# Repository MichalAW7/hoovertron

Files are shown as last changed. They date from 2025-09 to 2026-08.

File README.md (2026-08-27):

# Hoovertron: A Device for the Quantitative Measurement of Hoover's Sign

This repository contains the complete design files and software for the Hoovertron, a portable, floor-based device for the standardised, quantitative measurement of Hoover's sign. It provides a reliable, objective tool to aid diagnosis of functional leg weakness, a common feature of Functional Neurological Disorder (FND).

Based on: *Quantitative Measurement of Hoover's sign: development of a standardised sensor, interface procedure and testing in healthy individuals*.

## Repository Structure

```
hoovertron/
├── hardware/
│   ├── mechanical/          # SolidEdge source + STL/3MF/GCODE exports
│   │   ├── source/v1-main-part/
│   │   ├── source/v2-revised/
│   │   └── exports/{stl,3mf,gcode}/
│   └── pcb/
│       ├── src/             # Altium Designer source (SchDoc, PcbDoc, SchLib, PcbLib, PrjPcb)
│       └── outputs/         # Gerbers / CAM (generated, gitignored)
├── firmware/
│   ├── HVR_code_BLE_V3/     # Canonical Arduino Nano 33 BLE firmware (latest, with dummy-load fix)
│   └── archive/
│       ├── HVR_code_BLE_V2/ # Previous BLE version
│       ├── HVR_code_BLE_V1/
│       ├── HVR_code_v5/
│       └── FND_code_v4/
├── software/
│   ├── gui/                 # Canonical desktop GUI (Python + PyQt5 + bleak)
│   │   ├── main.py
│   │   ├── hoover_logic.py, ui_layout.py, config.py
│   │   ├── hoover_backend/  # ble_mixin, data_mixin, file_mixin, serial_mixin
│   │   ├── ui_components/   # menu_bar, patient_tab, results_tab, step_tabs
│   │   ├── images/
│   │   ├── Documentation/   # ARCHITECTURE, QUICK_START, etc.
│   │   ├── requirements.txt
│   │   └── HooverTron.spec / compile_app.bat
│   └── archive/
│       ├── bluetooth-v1/    # Legacy single-file BLE prototype
│       ├── bluetooth-v2/    # Pre-stylesheet modular version
│       └── gui-monolith/    # HooverTron.py monolith (pre-modular)
├── docs/
│   ├── manual/              # hoovertron_manual.md/.tex, canva_prompt.md
│   ├── images/              # Consolidated screenshots/infographics
│   └── screenshots/
├── .gitignore
└── LICENSE.md
```

## Hardware

### Mechanical
Custom 3D-printed housing isolates the heel on the sensor. Source in `hardware/mechanical/source/` (SolidEdge `.par`), printable exports in `hardware/mechanical/exports/` (`stl/` for printing, `3mf` for project, `gcode/` for slicer). See `hardware/mechanical/README.md` for print settings.

### Electronics
Custom PCB (Altium) in `hardware/pcb/src/`:
- **MCU:** Arduino Nano 33 BLE (or Nano Every for wired) - data acquisition & BLE/Serial
- **Sensor:** Ohmite FSR01CE force sensing resistor in voltage divider with 180 Ω, buffered via MCP6002 voltage follower, 3x 100nF decoupling/filter
- **Power:** USB or battery pack (V3 firmware pulses D2 with 100-220Ω dummy load to keep pack awake)

Gerber/BOM outputs are in `hardware/pcb/outputs/` (regenerable, ignored by git).

## Firmware

Canonical: `firmware/HVR_code_BLE_V3/HVR_code_BLE_V3.ino` (ArduinoBLE, 12-bit ADC 0-4095, dual-channel A0/A1, exponential force calibration `0.8259*exp(0.8623*V)...`, bilinear LPF `alpha=(2-2π0.001f)/(2+2π0.001f)`, BLE service `180D` char `2A37`, serial `F<freq>` command).

Upload with Arduino IDE (board: Nano 33 BLE, baud 115200).

Legacy versions in `firmware/archive/`.

## Software

### Requirements
```bash
pip install -r software/gui/requirements.txt
# PyQt5>=5.15.0, bleak>=0.20.0, qasync, numpy, matplotlib, pyqtgraph
```

### Run
```bash
python software/gui/main.py
# or build exe:
software/gui/compile_app.bat   # uses HooverTron.spec
```

Features: BLE/Serial connect, real-time force plot (N vs s), region select for max voluntary/involuntary, IV/V ratio, CSV logging.

### Documentation
- `software/gui/Documentation/QUICK_START.md` - install & run
- `software/gui/Documentation/ARCHITECTURE.md` - backend mixins + UI components
- `docs/manual/hoovertron_manual.md` - full manual

## Data Privacy
`patient data.csv` is gitignored. Do not commit patient data. Use anonymized examples only.

## License
MIT - see [LICENSE.md](LICENSE.md)

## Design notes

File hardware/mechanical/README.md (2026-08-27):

# Mechanical - 3D Printed Parts

Source SolidEdge `.par` in `source/`, exports in `exports/`. Print `exports/stl` at 0.2mm, PLA, 20% infill. See original SolidEdge files for tolerances.

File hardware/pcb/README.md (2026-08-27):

# PCB - Altium

Source in `src/`: Sheet1.SchDoc, PCB1.PcbDoc, etc. Open `Hoovertron_wired.PrjPcb` in Altium. Outputs regenerable in `outputs/` (Gerbers, drills).

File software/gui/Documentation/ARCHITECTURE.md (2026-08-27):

# HooverTron BLE Architecture

## System Overview

```
┌─────────────────────────────────────────────────────────────┐
│                    HooverTron BLE System                     │
└─────────────────────────────────────────────────────────────┘

┌──────────────────────┐         WIRELESS          ┌──────────────────────┐
│   Arduino Nano 33    │◄────────  BLE  ──────────►│   Python Application │
│        BLE           │      (~10-30 meters)       │      (PyQt5)         │
└──────────────────────┘                            └──────────────────────┘
         │                                                      │
         │ Reads Sensors                                       │ Displays
         ▼                                                      ▼
┌──────────────────────┐                            ┌──────────────────────┐
│  Force Sensors       │                            │  Real-time Graphs    │
│  - Sensor 1 (A0)     │                            │  - Extension Force   │
│  - Sensor 2 (A1)     │                            │  - Voluntary Force   │
└──────────────────────┘                            │  - Involuntary Force │
                                                     │  - Data Analysis     │
                                                     │  - Database          │
                                                     └──────────────────────┘
```

## Data Flow

```
┌─────────────────────────────────────────────────────────────────────┐
│                          Data Processing Pipeline                    │
└─────────────────────────────────────────────────────────────────────┘

ARDUINO SIDE:
─────────────
1. Analog Read (A0, A1)
   ▼
2. 12-bit ADC Conversion (0-4095)
   ▼
3. Voltage Scaling (5V equivalent)
   ▼
4. Force Calibration (Exponential formula)
   ▼
5. Digital Filtering (Alpha/Beta filter)
   ▼
6. Format as CSV String
   ▼
7. BLE Transmission (Notify)
   │
   │  <<< WIRELESS BLUETOOTH >>>
   │
   ▼

PYTHON SIDE:
────────────
8. BLE Notification Received
   ▼
9. Data Buffering
   ▼
10. Parse CSV String
    ▼
11. Update Data Arrays
    ▼
12. Update Real-time Graphs
    ▼
13. Calculate Statistics
    ▼
14. Save to Database/File
```

## BLE Communication

```
┌─────────────────────────────────────────────────────────────────────┐
│                      Bluetooth Low Energy (BLE)                      │
└─────────────────────────────────────────────────────────────────────┘

SERVICE: "180D"
├── CHARACTERISTIC: "2A37"
    ├── Properties: READ | NOTIFY
    ├── Max Size: 64 bytes
    ├── Data Format: "Time,Force1,Force2,FilteredForce1"
    └── Update Rate: ~100 Hz (every 10ms)

CONNECTION FLOW:
─────────────────
Arduino                             Python App
   │                                    │
   │ 1. BLE.begin()                     │
   │ 2. Set name "HooverTron"           │
   │ 3. Advertise service               │
   │                                    │
   │              ◄─────────────── 4. Scan for devices
   │              ──────────────► 5. Device found!
   │              ◄─────────────── 6. Connect request
   │ 7. Connection accepted             │
   │              ──────────────► 8. Start notifications
   │                                    │
   │ 9. Loop: read sensors              │
   │ 10. Send data via BLE              │
   │              ──────────────► 11. Receive notification
   │                                 12. Process & display
   │                                    │
   │ (continuous data stream...)        │
   │              ──────────────►       │
   │              ──────────────►       │
   │                                    │
   │              ◄─────────────── 13. Disconnect request
   │ 14. Close connection               │
```

## Component Architecture

```
┌─────────────────────────────────────────────────────────────────────┐
│                           Arduino Firmware                           │
└─────────────────────────────────────────────────────────────────────┘

LIBRARIES:
- ArduinoBLE.h          → Bluetooth communication

MAIN COMPONENTS:
- BLEService            → Container for characteristics
- BLECharacteristic     → Data channel
- Sensor Reading        → analogRead() from A0, A1
- Digital Filter        → First-order filter implementation
- Data Formatting       → CSV string builder

LOOP CYCLE (every 10ms):
1. Check for BLE connection
2. Read sensors
3. Apply calibration
4. Apply filtering
5. Format data
6. Transmit via BLE

┌─────────────────────────────────────────────────────────────────────┐
│                        Python Application                            │
└─────────────────────────────────────────────────────────────────────┘

LIBRARIES:
- PyQt5                 → GUI framework
- bleak                 → BLE communication
- qasync                → Async/await with PyQt5
- numpy                 → Data processing
- matplotlib            → Plotting

MAIN COMPONENTS:
- HooverTronWindow      → Main application class
- BleakClient           → BLE connection handler
- BleakScanner          → Device discovery
- UI Layout             → PyQt5 GUI elements
- Data Arrays           → Force and time data storage
- File I/O              → CSV and config management
- Database Manager      → Patient data storage

EVENT LOOP:
- QEventLoop (qasync)   → Handles both GUI and async BLE events
```

## File Organization

```
AntiGravity/
├── Arduino Firmware
│   └── HVR_code_BLE_V1/
│       └── HVR_code_BLE_V1.ino      ← BLE-enabled firmware
│
├── Python Application
│   ├── main.py                       ← Entry point (async event loop)
│   ├── hoover_logic.py               ← BLE logic + data processing
│   ├── ui_layout.py                  ← GUI definition
│   └── config.py                     ← Configuration paths
│
├── Setup & Dependencies
│   ├── requirements.txt              ← Python packages
│   └── install_dependencies.bat      ← Windows installer
│
└── Documentation
    ├── README_BLE.md                 ← Full documentation
    ├── QUICK_START.md                ← Getting started guide
    ├── CHANGES_SUMMARY.md            ← What changed
    └── ARCHITECTURE.md               ← This file
```

## Key Design Decisions

### Why These UUIDs?
- **Service 180D**: Standard "Heart Rate" service UUID
  - Chosen for compatibility and simplicity
  - Repurposed for sensor data transmission
  
- **Characteristic 2A37**: Standard "Heart Rate Measurement"
  - READ | NOTIFY properties
  - Perfect for continuous data streaming

### Why bleak Library?
- Cross-platform (Windows, macOS, Linux)
- Modern async/await API
- Well-maintained and documented
- Native OS BLE stack integration

### Why qasync?
- Bridges asyncio and PyQt5
- Allows async BLE operations without blocking GUI
- Clean integration of both event loops

### Why Keep Serial?
- Debugging during development
- Firmware verification
- Troubleshooting sensor issues
- Future diagnostics

## Performance Characteristics

**Latency:**
- BLE notification delay: ~10-20ms
- Processing time: <1ms
- GUI update rate: ~100 Hz
- Total system latency: ~20-30ms

**Throughput:**
- Data packet size: ~30 bytes
- Update frequency: 100 Hz
- Bandwidth usage: ~3 KB/s
- BLE capacity: Up to 1 MB/s

**Range:**
- Indoor: 10-15 meters
- Outdoor: 20-30 meters
- Through walls: 5-10 meters

**Power Consumption:**
- BLE transmission: ~15 mA
- Sensor reading: ~5 mA
- Microcontroller: ~10 mA
- **Total: ~30 mA** (can run on battery)

## Security Considerations

**Current Implementation:**
- No encryption (open connection)
- No authentication required
- Any device can connect

**Future Enhancements:**
- Pairing/bonding support
- Encrypted characteristic
- Password protection
- MAC address filtering

## Comparison: Serial vs BLE

```
┌──────────────────┬────────────────────┬────────────────────┐
│    Feature       │    Serial/USB      │        BLE         │
├──────────────────┼────────────────────┼────────────────────┤
│ Connection       │ Wired (USB cable)  │ Wireless (BLE)     │
│ Range            │ <5 meters          │ 10-30 meters       │
│ Mobility         │ Tethered           │ Free movement      │
│ Power            │ USB powered        │ Battery possible   │
│ Latency          │ <5ms               │ ~20ms              │
│ Bandwidth        │ 115200 baud        │ ~1 Mbps            │
│ Setup            │ COM port selection │ Auto-discovery     │
│ Reliability      │ Very high          │ High               │
│ Interference     │ None               │ Possible (rare)    │
│ Multiple devices │ Complex            │ Easier             │
└──────────────────┴────────────────────┴────────────────────┘
```

## Future Expansion Possibilities

1. **Multiple Sensors:**
   - Connect multiple Arduino units
   - Synchronized data collection
   - Comparative analysis

2. **Mobile App:**
   - iOS/Android application
   - Tablet-based interface
   - Cloud data sync

3. **Data Analytics:**
   - Machine learning integration
   - Pattern recognition
   - Automated diagnostics

4. **Remote Monitoring:**
   - WiFi gateway
   - Internet connectivity
   - Remote expert consultation

5. **Enhanced Features:**
   - Battery level indicator
   - Signal strength display
   - Automatic reconnection
   - Data logging on Arduino

## Conclusion

The BLE implementation provides a modern, wireless solution while maintaining 100% functional compatibility with the original serial-based system. The modular architecture allows for easy future enhancements and expansions.

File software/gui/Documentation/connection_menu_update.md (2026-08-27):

# HooverTron Connection Menu Update

## Summary of Changes

### 1. New "Connection" Menu Tab
- Created a new menu tab called "Connection" positioned between "Database" and "Help"
- Moved Bluetooth device management from "Edit" menu to this new "Connection" menu
- The menu name is "Bluetooth" instead of "BLE Device" for clarity

### 2. Automatic Connection Feature
- The application now automatically scans for devices with "hoovertron" in the name (case-insensitive)
- When found, the device is:
  - Automatically selected
  - Marked with a ★ symbol in the device list
  - Automatically connected
- If no hoovertron device is found, the app performs a regular scan and displays all available devices

### 3. Manual Connection Fallback
- If automatic connection fails, users can still manually:
  - Scan for devices using "Scan for Devices" option
  - Select any available BLE device from the list
  - Click "Connect" to establish connection

### 4. Files Modified
- **menu_bar.py**: Added "Connection" menu and integrated BLE device manager
- **add_ble_device.py**: Added auto_scan_and_connect() method for automatic connection
- **hoover_logic.py**: Recreated main window class integrating all backend mixins

### 5. How It Works
1. Application starts
2. BLE manager automatically scans for devices
3. Looks for "hoovertron" device
4. If found: auto-selects and connects
5. If not found: displays message and shows all available devices
6. User can manually connect if needed

### 6. Status Messages
The status bar shows:
- "Searching for HooverTron device..." during scan
- "Found HooverTron: [name]. Auto-connecting..." when device is found
- "HooverTron device not found. Please scan and connect manually." if not found
- Connection status updates

## Usage
1. Start the application
2. The Connection menu appears between Database and Help
3. Click Connection → Bluetooth to see device options
4. The hoovertron device (if available) will be auto-selected and connected
5. If manual connection needed: Click "Scan for Devices" then "Connect"

## Benefits
- Streamlined workflow with automatic connection
- Clear menu organization with dedicated Connection tab
- Better user experience with status messages
- Fallback to manual connection ensures flexibility

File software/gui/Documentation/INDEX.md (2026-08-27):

# 📡 HooverTron BLE - Documentation Index

Welcome to the HooverTron Bluetooth Low Energy implementation! This index will guide you to the right documentation for your needs.

---

## 🚀 Getting Started (First Time Users)

**Start Here → [QUICK_START.md](QUICK_START.md)**
- Step-by-step setup instructions
- Arduino firmware upload guide
- Python installation
- First connection tutorial
- Basic troubleshooting

**Estimated Time:** 10-15 minutes

---

## 📚 Documentation Guide

### For Users

| Document | Purpose | When to Read |
|---|---|---|
| **[QUICK_START.md](QUICK_START.md)** | Quick setup & usage | First time setup |
| **[README_BLE.md](README_BLE.md)** | Complete user manual | Detailed information needed |
| **Troubleshooting** (in README_BLE.md) | Fix common issues | When things don't work |

### For Developers

| Document | Purpose | When to Read |
|---|---|---|
| **[ARCHITECTURE.md](ARCHITECTURE.md)** | System design & data flow | Understanding the system |
| **[CHANGES_SUMMARY.md](CHANGES_SUMMARY.md)** | What changed from serial | Migration from old version |
| **Code files** | Implementation details | Modifying the code |

---

## 📁 File Structure & Purpose

### Arduino Firmware
```
HVR_code_BLE_V1/
└── HVR_code_BLE_V1.ino         Arduino code with BLE support
```

### Python Application
```
main.py                          Entry point - run this to start
hoover_logic.py                  BLE communication & data processing  
ui_layout.py                     GUI interface definition
config.py                        Configuration file paths
add_comport.py                   Legacy COM port utilities
```

### Setup Scripts
```
requirements.txt                 Python dependencies list
install_dependencies.bat         Windows installer script
```

### Documentation
```
INDEX.md                         This file - start here
QUICK_START.md                   Fast setup guide
README_BLE.md                    Complete documentation
ARCHITECTURE.md                  Technical design details
CHANGES_SUMMARY.md               Migration guide
```

---

## 🎯 Common Tasks

### "I want to set this up for the first time"
→ Read **[QUICK_START.md](QUICK_START.md)**

### "Something isn't working"
→ Check **Troubleshooting** section in **[README_BLE.md](README_BLE.md)**

### "I need to understand how BLE communication works"
→ Read **[ARCHITECTURE.md](ARCHITECTURE.md)**

### "I'm upgrading from the serial version"
→ Read **[CHANGES_SUMMARY.md](CHANGES_SUMMARY.md)**

### "I want to modify the code"
→ Read **[ARCHITECTURE.md](ARCHITECTURE.md)** first, then examine the code files

### "I need installation help"
→ Run **install_dependencies.bat** OR see Setup sections in **[QUICK_START.md](QUICK_START.md)**

### "I want to know what's different from before"
→ Read **[CHANGES_SUMMARY.md](CHANGES_SUMMARY.md)**

---

## ⚡ Quick Reference

### System Requirements
- **Hardware:** Arduino Nano 33 BLE + Bluetooth 4.0+ computer
- **Software:** Python 3.7+ | Arduino IDE 1.8.10+
- **OS:** Windows 10+, macOS 10.15+, or Linux with BlueZ

### Key Information
- **Device Name:** HooverTron
- **BLE Service UUID:** 180D
- **BLE Characteristic UUID:** 2A37
- **Data Format:** `Time,Force1,Force2,FilteredForce1`
- **Update Rate:** ~100 Hz (every 10ms)
- **Range:** 10-30 meters

### Installation Commands
```bash
# Python dependencies
pip install -r requirements.txt

# Or use the batch script (Windows)
install_dependencies.bat
```

### Running the Application
```bash
python main.py
```

---

## 📖 Reading Order Recommendations

### For First-Time Users:
1. **QUICK_START.md** - Get up and running
2. **README_BLE.md** - Learn all features
3. **CHANGES_SUMMARY.md** - See what's new (if coming from serial version)

### For Developers:
1. **CHANGES_SUMMARY.md** - Understand modifications
2. **ARCHITECTURE.md** - Learn system design
3. **Code files** - Examine implementation
4. **README_BLE.md** - User perspective

### For Troubleshooting:
1. **QUICK_START.md** - Basic troubleshooting
2. **README_BLE.md** - Detailed troubleshooting
3. **ARCHITECTURE.md** - Technical debugging

---

## 🔧 Technical Specifications

### Arduino Side
- **Board:** Arduino Nano 33 BLE
- **Library:** ArduinoBLE (by Arduino)
- **ADC Resolution:** 12-bit (0-4095)
- **Sampling Rate:** 100 Hz
- **BLE Role:** Peripheral (server)

### Python Side
- **Framework:** PyQt5
- **BLE Library:** bleak
- **Async Integration:** qasync
- **Data Processing:** numpy, matplotlib
- **BLE Role:** Central (client)

---

## 📞 Support Resources

### Included Documentation
- All troubleshooting steps in README_BLE.md
- Architecture diagrams in ARCHITECTURE.md
- Setup procedures in QUICK_START.md
- Change details in CHANGES_SUMMARY.md

### Code Comments
- Arduino firmware has inline comments
- Python code has docstrings and comments
- Both explain key algorithms and BLE operations

### Serial Debugging
- Arduino Serial Monitor (115200 baud)
- Python console output
- Both provide real-time debugging information

---

## ✨ What Makes This Special

### Key Features
✅ **Wireless Freedom** - No USB cables required  
✅ **Real-time Data** - 100 Hz update rate  
✅ **Long Range** - Up to 30 meters  
✅ **Low Power** - Battery operation possible  
✅ **Auto-Discovery** - No manual device selection  
✅ **Full Compatibility** - All original features preserved  

### What Changed
🔄 Communication: Serial → BLE  
🔄 Connection: Wired → Wireless  

### What Stayed The Same
✓ All data processing  
✓ All UI elements  
✓ All file operations  
✓ All graphing features  
✓ All patient management  
✓ All calculations  

---

## 📝 Version Information

**Version:** BLE v1.0  
**Date:** November 2025  
**Hardware:** Arduino Nano 33 BLE  
**Communication:** Bluetooth Low Energy 4.0+  

**Previous Version:** Serial/USB based  
**Migration Path:** See CHANGES_SUMMARY.md  

---

## 🎓 Learning Path

### Beginner
1. ✅ Setup (QUICK_START.md)
2. ✅ Basic usage (README_BLE.md - Usage section)
3. ✅ Troubleshooting basics (QUICK_START.md)

### Intermediate
1. ✅ Full features (README_BLE.md)
2. ✅ Understanding changes (CHANGES_SUMMARY.md)
3. ✅ Basic modifications (code files)

### Advanced
1. ✅ System architecture (ARCHITECTURE.md)
2. ✅ BLE protocol details (ARCHITECTURE.md)
3. ✅ Code modifications (all source files)
4. ✅ Custom enhancements (extend the system)

---

## 🚦 Status Indicators

### Arduino
- **Serial Output:** "BLE device active, waiting for connections..."
  - ✅ BLE initialized successfully
  
- **Serial Output:** "Connected to central: [MAC]"
  - ✅ Python app connected

### Python Application
- **Console:** "Scanning for HooverTron device..."
  - 🔍 Searching for Arduino
  
- **Console:** "Connected to HooverTron"
  - ✅ Connection established
  
- **Console:** "Notifications started"
  - ✅ Data streaming active

---

## 🎯 Remember

**👉 Start with [QUICK_START.md](QUICK_START.md) if this is your first time!**

**👉 Check [README_BLE.md](README_BLE.md) for comprehensive documentation!**

**👉 Read [ARCHITECTURE.md](ARCHITECTURE.md) to understand the system design!**

---

Happy Testing! 🔬📊🚀

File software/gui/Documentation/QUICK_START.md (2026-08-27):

# Quick Start Guide - HooverTron BLE

## For First-Time Setup

### Step 1: Arduino Setup (5 minutes)

1. **Open Arduino IDE**

2. **Install ArduinoBLE Library:**
   - Click: `Sketch` → `Include Library` → `Manage Libraries...`
   - Search: "ArduinoBLE"
   - Click: Install on "ArduinoBLE by Arduino"
   - Wait for installation to complete

3. **Select Your Board:**
   - Click: `Tools` → `Board` → `Arduino Mbed OS Nano Boards` → `Arduino Nano 33 BLE`
   - Click: `Tools` → `Port` → Select your COM port

4. **Upload the Firmware:**
   - Open: `HVR_code_BLE_V1/HVR_code_BLE_V1.ino`
   - Click: Upload button (→)
   - Wait for "Done uploading" message

5. **Verify It Works:**
   - Open: `Tools` → `Serial Monitor`
   - Set baud rate: 115200
   - You should see: "BLE device active, waiting for connections..."

### Step 2: Python Setup (2 minutes)

1. **Install Dependencies:**
   - Double-click: `install_dependencies.bat`
   - OR run in terminal: `pip install -r requirements.txt`
   - Wait for installation to complete

### Step 3: Run the Application (30 seconds)

1. **Power the Arduino:**
   - Connect Arduino to USB or battery
   - Blue LED should be on

2. **Start the Application:**
   - Double-click or run: `python main.py`
   - The HooverTron window will open

3. **Connect and Record:**
   - Click the **Record** button
   - Wait 2-5 seconds for BLE connection
   - Button changes to **Stop** when connected
   - Data should appear on the graph

4. **When Finished:**
   - Click **Stop** to disconnect
   - Close the application

## Troubleshooting

### "HooverTron device not found"
- ✅ Check Arduino is powered on
- ✅ Check Arduino uploaded successfully (look for Serial Monitor output)
- ✅ Make sure Bluetooth is enabled on your computer
- ✅ Move Arduino closer to your computer
- ✅ Try restarting the Arduino (unplug and replug)

### "Starting BLE failed!" in Serial Monitor
- ✅ Make sure you selected **Arduino Nano 33 BLE** (not other boards)
- ✅ Re-upload the sketch
- ✅ Try a different USB cable

### Python Import Errors
- ✅ Run: `pip install -r requirements.txt`
- ✅ Make sure you're using Python 3.7+
- ✅ Try: `python --version` to check

### No Data on Graphs
- ✅ Check sensor connections to A0 and A1
- ✅ Verify sensors are powered
- ✅ Check Serial Monitor for raw data output

## Daily Use (After Initial Setup)

1. Power on Arduino
2. Run: `python main.py`
3. Click **Record**
4. Perform tests
5. Click **Stop**
6. Save data if needed

## Features Available

- ✅ Real-time data visualization
- ✅ Three test protocols (Extension, Voluntary, Involuntary)
- ✅ Peak and average force calculations
- ✅ IVVR (Involuntary/Voluntary Ratio) calculation
- ✅ Patient database management
- ✅ Save/Load test data (CSV format)
- ✅ Time period selection for analysis
- ✅ Filter frequency adjustment

## File Structure

```
AntiGravity/
├── HVR_code_BLE_V1/
│   └── HVR_code_BLE_V1.ino    ← Arduino firmware
├── main.py                     ← Run this to start app
├── hoover_logic.py             ← Application logic
├── ui_layout.py                ← UI definition
├── config.py                   ← Configuration
├── requirements.txt            ← Python dependencies
├── install_dependencies.bat    ← Setup script
├── README_BLE.md              ← Full documentation
├── CHANGES_SUMMARY.md         ← What changed
└── QUICK_START.md             ← This file
```

## Getting Help

1. **Check README_BLE.md** - Full documentation with detailed troubleshooting
2. **Check CHANGES_SUMMARY.md** - Understanding what changed from serial version
3. **Check Serial Monitor** - Arduino debugging output at 115200 baud
4. **Check Console Output** - Python debugging information

## System Requirements

**Hardware:**
- Arduino Nano 33 BLE (required)
- Computer with Bluetooth 4.0+ support
- Force sensors connected to A0 and A1

**Software:**
- Windows 10+, macOS 10.15+, or Linux with BlueZ
- Python 3.7 or higher
- Arduino IDE 1.8.10 or higher

## Quick Reference

**BLE Connection:**
- Device Name: "HooverTron"
- Service UUID: 180D
- Characteristic UUID: 2A37
- Typical Range: 10-30 meters

**Data Format:**
- CSV: `Time,Force1,Force2,FilteredForce1`
- Update Rate: ~100 Hz (every 10ms)
- ADC Resolution: 12-bit (0-4095)

**Sensors:**
- Input Pins: A0 (Sensor 1), A1 (Sensor 2)
- Voltage Range: 0-3.3V
- Calibration: Exponential formula applied

## That's It!

You're ready to use the HooverTron BLE system. The wireless connection provides freedom of movement while maintaining all the functionality of the original system.

**Happy Testing! 🔬📊**

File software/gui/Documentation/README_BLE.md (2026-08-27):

# HooverTron BLE Implementation

## Overview
This project has been updated to use **Bluetooth Low Energy (BLE)** for wireless communication between the Arduino Nano 33 BLE and the Python application, replacing the previous serial (COM port) communication.

## Changes Made

### Arduino Firmware (`HVR_code_BLE_V1.ino`)
- **Added BLE Support**: Integrated the ArduinoBLE library for wireless communication
- **BLE Service**: Custom service UUID `180D` for sensor data
- **BLE Characteristic**: Custom characteristic UUID `2A37` with Read and Notify properties
- **Data Transmission**: Sensor data is now transmitted via BLE notifications instead of Serial
- **Device Name**: The Arduino advertises as "HooverTron" for easy identification
- **Maintained Functionality**: All sensor reading, filtering, and data processing logic remains unchanged

### Python Application (`hoover_logic.py`)
- **Removed Serial Communication**: Replaced `QtSerialPort` with BLE using the `bleak` library
- **Async/Await Pattern**: Implemented asynchronous BLE operations for non-blocking communication
- **BLE Scanner**: Automatically scans and connects to "HooverTron" device
- **Notification Handler**: Receives data from Arduino via BLE notifications
- **Data Buffer**: Implements buffering to handle fragmented BLE packets
- **Maintained UI**: All existing UI functionality remains exactly the same
- **Error Handling**: Added robust error handling for BLE connection issues

### Main Entry Point (`main.py`)
- **Event Loop**: Integrated `qasync` to enable async operations within PyQt5
- **BLE Support**: Set up proper async event loop for BLE operations

## Installation

### 1. Arduino Setup
1. Open `HVR_code_BLE_V1/HVR_code_BLE_V1.ino` in Arduino IDE
2. Install the **ArdulinoBLE** library:
   - Go to `Sketch` → `Include Library` → `Manage Libraries`
   - Search for "ArduinoBLE"
   - Install the library by Arduino
3. Select your **Arduino Nano 33 BLE** board:
   - Go to `Tools` → `Board` → `Arduino Mbed OS Nano Boards` → `Arduino Nano 33 BLE`
4. Upload the sketch to your Arduino Nano 33 BLE

### 2. Python Setup
Install the required dependencies:
```bash
pip install -r requirements.txt
```

The main dependencies are:
- **bleak**: Python BLE library for cross-platform Bluetooth communication
- **qasync**: Integration layer for asyncio and PyQt5
- **PyQt5**: GUI framework
- **numpy & matplotlib**: Data processing and visualization

## Usage

### 1. Power On the Arduino
- Connect the Arduino Nano 33 BLE to a power source (USB or battery)
- The device will start advertising as "HooverTron"
- The onboard LED may blink to indicate BLE is active

### 2. Run the Python Application
```bash
python main.py
```

### 3. Connect to the Device
1. Click the **Record** button in the application
2. The app will automatically scan for the "HooverTron" device
3. Once found, it will connect and start receiving data
4. The button will change to **Stop** when connected
5. Click **Stop** to disconnect

### 4. If Connection Fails
- Ensure the Arduino is powered on and nearby (within BLE range, ~10 meters)
- Make sure no other application is connected to the Arduino
- Check that Bluetooth is enabled on your computer
- Try restarting both the Arduino and the Python application

## Technical Details

### BLE UUIDs
- **Service UUID**: `180D` (Heart Rate Service - repurposed for sensor data)
- **Characteristic UUID**: `2A37` (Heart Rate Measurement - repurposed for sensor data)

### Data Format
Data is transmitted in the same CSV format as before:
```
Time,Force1,Force2,FilteredForce1
```

Example:
```
10523,2.456,1.234,2.123
```

### BLE Data Transmission
- **Packet Size**: Up to 64 bytes per notification
- **Update Rate**: Approximately every 10ms (100 Hz)
- **Range**: Typical BLE range is 10-30 meters depending on environment

## Advantages of BLE over Serial

1. **Wireless**: No USB cable required
2. **Mobility**: The Arduino can be battery-powered and portable
3. **Multiple Connections**: Potentially connect to multiple devices (future enhancement)
4. **Lower Power**: BLE is designed for low power consumption
5. **Modern Standard**: BLE is widely supported across devices

## Troubleshooting

### Arduino Won't Upload
- Make sure you've selected the correct board: `Arduino Nano 33 BLE`
- Ensure the USB cable supports data transfer (not power-only)
- Try pressing the reset button twice quickly to enter bootloader mode

### Python App Can't Find Device
- Check that the Arduino sketch is uploaded and running
- Verify Bluetooth is enabled on your computer
- Ensure you're within BLE range (~10 meters)
- Try running the scan with elevated privileges (admin/sudo)

### Data Not Appearing
- Check the sensor connections to pins A0 and A1
- Verify the calibration formulas are appropriate for your sensors
- Monitor the Arduino Serial output (115200 baud) for debugging info

### BLE Connection Drops
- Reduce distance between Arduino and computer
- Minimize interference from other wireless devices
- Ensure Arduino has stable power supply

## Future Enhancements

Potential improvements for future versions:
- Add battery level monitoring
- Implement automatic reconnection
- Support multiple simultaneous sensor units
- Add data encryption for secure transmission
- Implement configuration via BLE (e.g., filter frequency)

## Notes

- The Serial communication in the Arduino code is kept for debugging purposes
- The Python app maintains backward compatibility with the file format
- All existing features (file save/load, database, graphs) work exactly as before
- Only the communication layer has changed from Serial to BLE

## Support

For issues or questions, please ensure:
1. You're using Arduino Nano 33 BLE (not other Nano variants)
2. The ArduinoBLE library is properly installed
3. Python dependencies are installed: `pip install -r requirements.txt`
4. Your operating system supports BLE (Windows 10+, macOS 10.15+, Linux with BlueZ)

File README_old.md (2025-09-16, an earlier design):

# Hoovertron: A Device for the Quantitative Measurement of Hoover's Sign

This repository contains the complete design files and software for the Hoovertron, a portable, floor-based device developed for the standardised, quantitative measurement of Hoover's sign. The project aims to provide a reliable and objective tool to aid in the diagnosis of functional leg weakness, a common feature of Functional Neurological Disorder (FND).

This work is based on the research paper: *Quantitative Measurement of Hoover's sign: development of a standardised sensor, interface procedure and testing in healthy individuals*.

## Project Overview

Hoover's sign is a clinical sign used to help diagnose functional weakness of a leg. It relies on the principle of synergistic contraction: an involuntary downward force (hip extension) is generated in one leg when the opposite leg's hip is actively flexed against resistance. In functional weakness, this involuntary force is often greater than the voluntary force the person can generate, a discrepancy that the Hoovertron is designed to measure.

The Hoovertron provides a reliable method to quantify and record the voluntary and involuntary forces, calculating the Involuntary/Voluntary (IV/V) force ratio to offer an objective measure.

## Repository Structure

This project is organized into the following directories:

*   **/3D Parts - SolidEdge**: Contains the SolidEdge CAD files for the 3D-printed components of the device, including the main housing and footrest.
*   **/PCB - Altium**: Contains the Altium Designer files for the custom Printed Circuit Board (PCB) that houses the sensor interface electronics.
*   **/Arduino - C++**: Contains the firmware source code for the Arduino Nano Every microcontroller. This code is responsible for reading data from the force sensor, processing it, and transmitting it to the PC.
*   **/GUI - Python**: Contains the source code for the desktop Graphical User Interface (GUI) developed in Python with PyQt5. This application receives, visualizes, and analyzes the force data.

## Hardware

### Mechanical Components
The device housing is custom-designed to isolate the heel and ensure that downward force is applied directly to the sensor.
*   **3D Printed Housing:** A custom-made chassis that holds the electronics and force sensor.
*   **Foot Support & Footrest:** Ensures correct placement of the heel on the sensor.

### Electronics
The electronic components are mounted on a custom PCB. The core components include:
*   **Microcontroller:** An Arduino Nano Every is used for data acquisition and communication.
*   **Force Sensor:** An Ohmite FSR01CE Force Sensing Resistor measures the downward pressure exerted by the heel. The PCB is designed to accommodate two sensors (PS1 and PS2), but the current implementation uses only one.
*   **Signal Conditioning:** The signal from the active sensor is conditioned using an MCP6002 Op-Amp. The sensor is configured in a voltage divider circuit with a 180 Ω resistor. Three 100 nF capacitors are used to improve signal stability: one across the resistor for filtering and two for power supply decoupling. The op-amp is connected as a voltage follower to buffer the signal before it is read by the Arduino's analog-to-digital converter, preventing measurement inaccuracies due to loading effects.
*   **Power:** The entire device is powered via the USB connection to the PC.

## Software

### Arduino Firmware
The C++ firmware running on the Arduino Nano Every performs the following tasks:
1.  Reads the analog voltage from the force sensor circuit.
2.  Applies a calibration curve to convert the voltage reading into a force value in Newtons (N).
3.  Implements a digital low-pass filter to provide a stable, averaged output.
4.  Communicates the force data to the host PC via a serial-over-USB connection.

### Python GUI Application
The user-facing application is built using Python and PyQt5. Its features include:
1.  **Serial Communication:** Establishes a connection with the Arduino to receive real-time force data.
2.  **Data Visualization:** Plots the force (N) over time (s) in a user-friendly graph.
3.  **Data Analysis:** Allows the user to select a time period on the graph to determine the maximum force for both voluntary and involuntary measurements.
4.  **IV/V Ratio Calculation:** Automatically calculates the Involuntary/Voluntary force ratio based on the recorded measurements.
5.  **Data Logging:** Saves test results and patient information to CSV files for record-keeping and further analysis.

This project is licensed under the MIT License - see the [LICENSE.md](LICENSE.md) file for details.

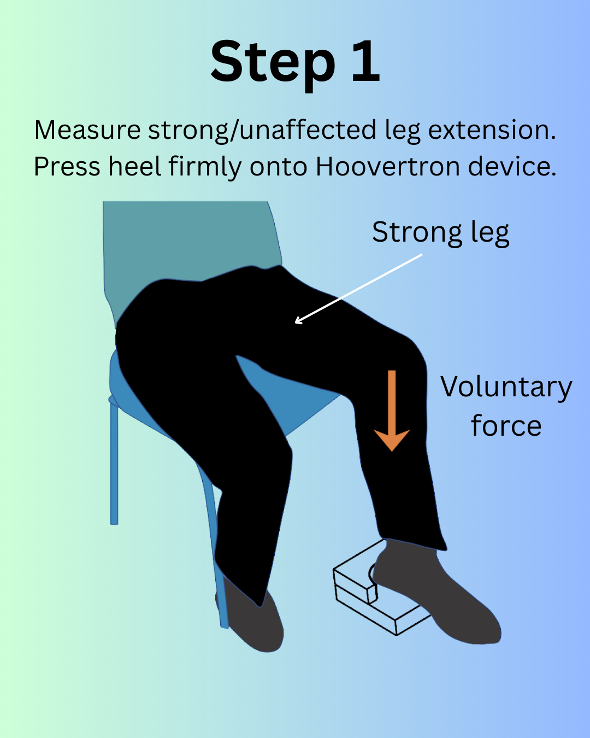
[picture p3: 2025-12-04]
docs/images/infographic1.drawio.png

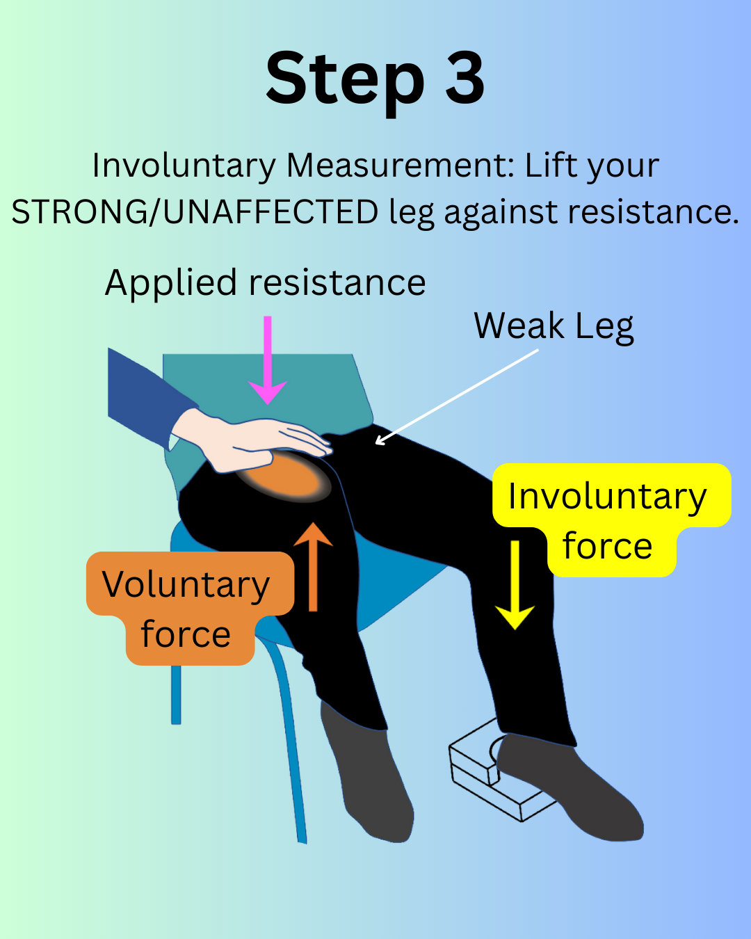
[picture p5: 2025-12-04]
docs/images/infographic3.drawio.png

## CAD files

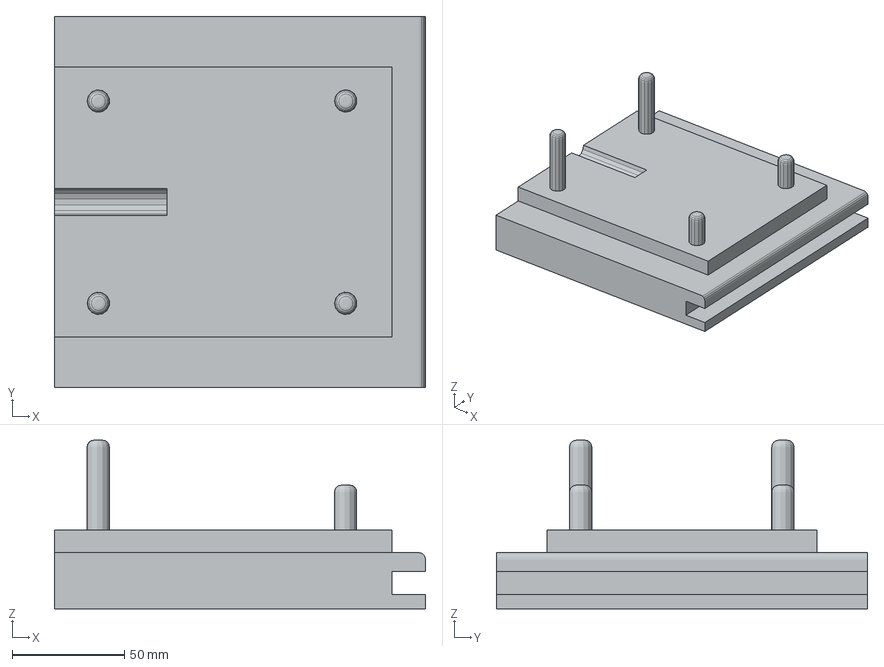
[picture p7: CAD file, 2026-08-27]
hardware/mechanical/exports/3mf/Main_Part.3mf
165.0 x 165.0 x 75.0 mm

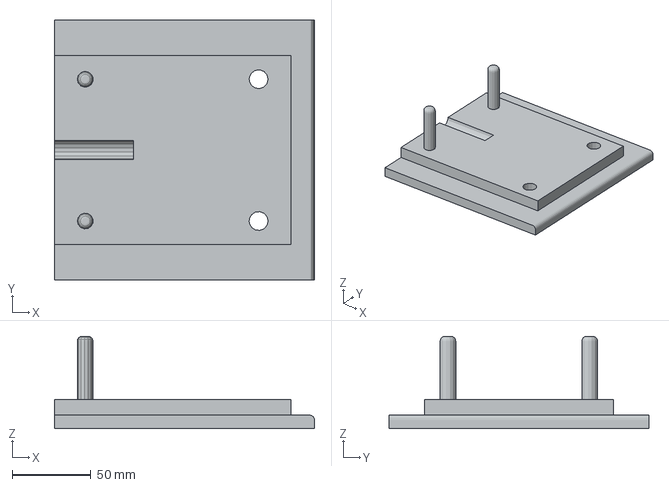
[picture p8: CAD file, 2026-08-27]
hardware/mechanical/exports/3mf/Top.3mf
165.0 x 165.0 x 58.6 mm

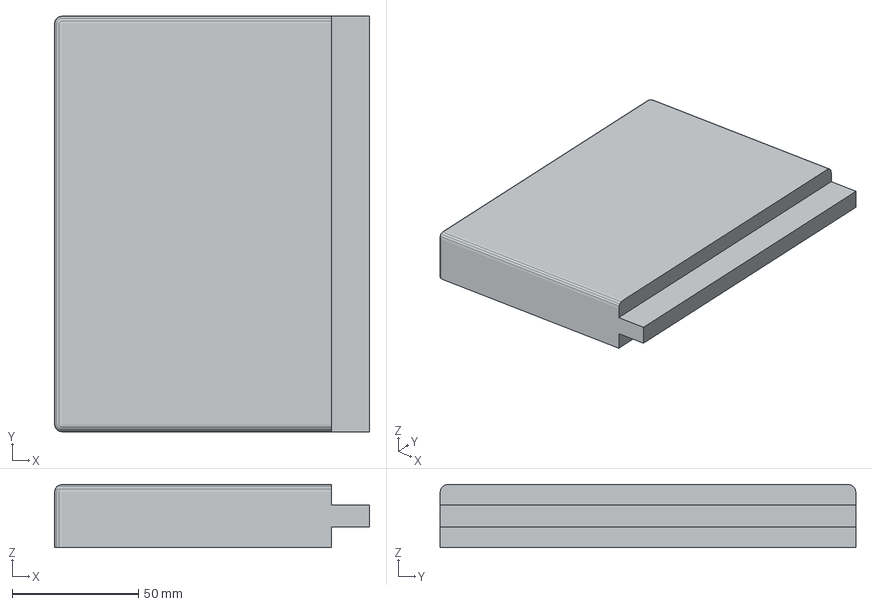
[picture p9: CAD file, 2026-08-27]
hardware/mechanical/exports/3mf/Foot_extender.3mf
125.0 x 165.0 x 25.0 mm

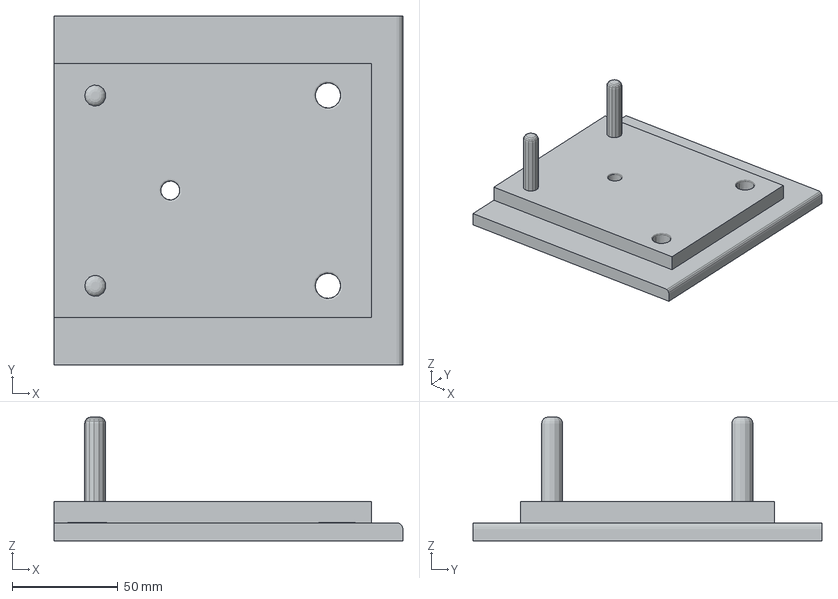
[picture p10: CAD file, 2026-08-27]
hardware/mechanical/exports/3mf/Top_V4.3mf
165.0 x 165.0 x 58.6 mm

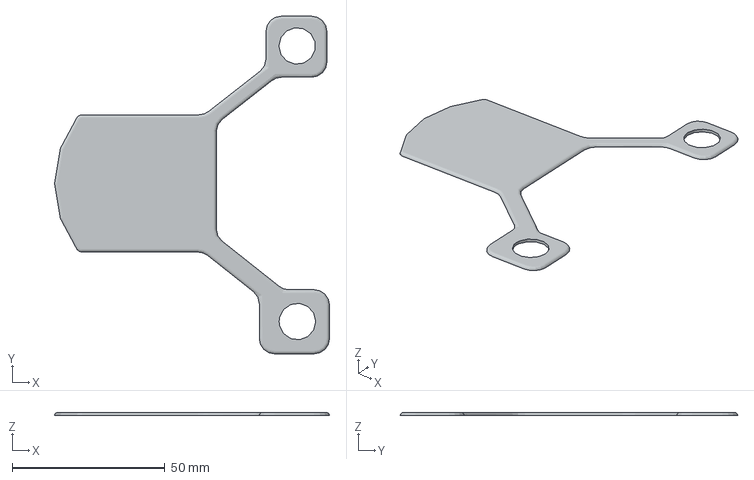
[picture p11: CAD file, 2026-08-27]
hardware/mechanical/exports/3mf/Sensor_Cover.3mf
90.1 x 110.6 x 1.00 mm

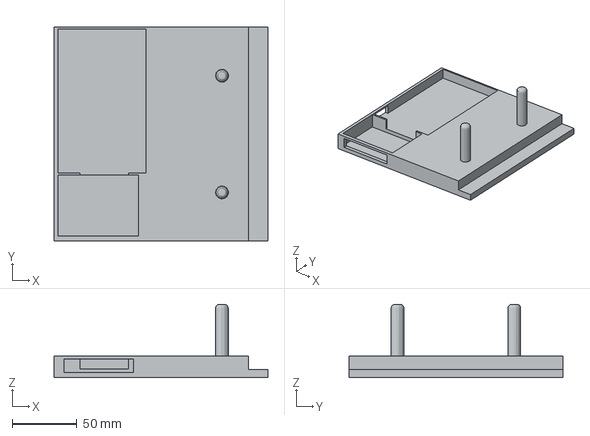
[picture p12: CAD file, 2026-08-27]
hardware/mechanical/exports/3mf/Bottom.3mf
165.0 x 165.0 x 56.6 mm

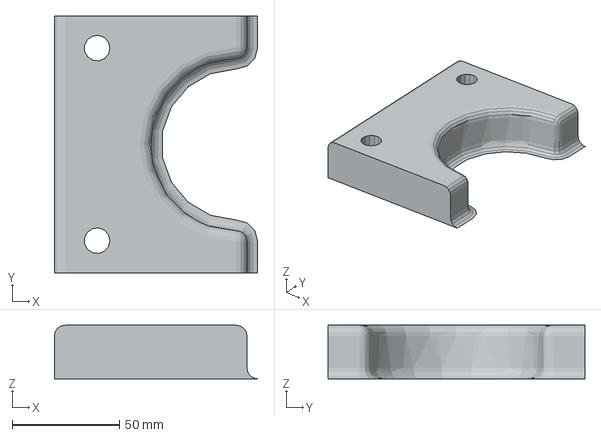
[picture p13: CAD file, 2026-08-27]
hardware/mechanical/exports/3mf/Foot_aligner.3mf
95.0 x 120.0 x 25.0 mm

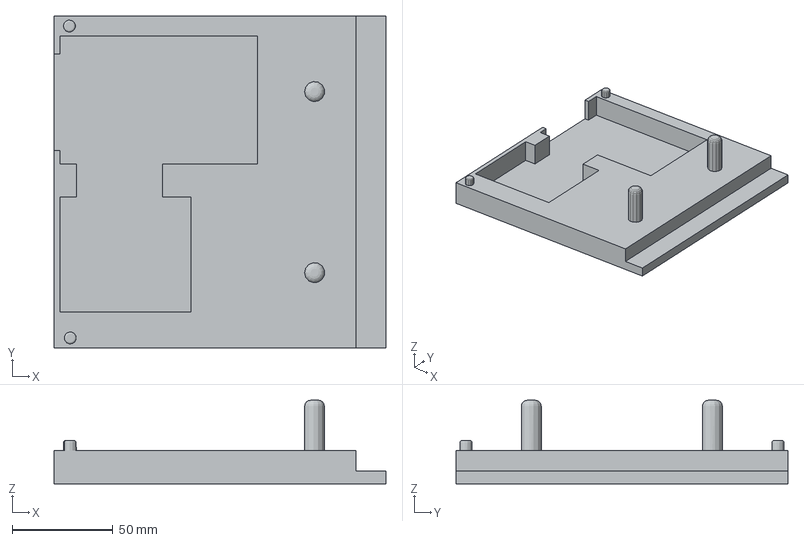
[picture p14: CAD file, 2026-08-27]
hardware/mechanical/exports/3mf/Bottom_V6.3mf
165.0 x 165.0 x 41.6 mm

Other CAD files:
hardware/mechanical/exports/gcode/Hoovertron_Main_Part_V2.gcode.3mf
hardware/mechanical/exports/gcode/Main_Part.gcode.3mf
hardware/mechanical/exports/3mf/Hoovertron_Main_Part_V2.3mf
hardware/mechanical/exports/gcode/Top.gcode.3mf
hardware/mechanical/exports/gcode/Foot_extender.gcode.3mf
hardware/mechanical/exports/gcode/Bottom.gcode.3mf
hardware/mechanical/exports/gcode/Foot_aligner.gcode.3mf
hardware/mechanical/exports/gcode/Top_V4.gcode.3mf
hardware/mechanical/exports/gcode/Bottom_V6.gcode.3mf
hardware/mechanical/exports/gcode/Sensor_Cover.gcode.3mf
hardware/mechanical/exports/3mf/BottomV3.3mf
hardware/mechanical/exports/3mf/Bottom_V2.3mf
hardware/mechanical/exports/3mf/Bottom_V4.3mf
hardware/mechanical/exports/3mf/Bottom_v5.3mf
hardware/mechanical/exports/3mf/TopV3.3mf
hardware/mechanical/exports/3mf/Top_V2.3mf
hardware/mechanical/exports/gcode/BottomV3.gcode.3mf
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

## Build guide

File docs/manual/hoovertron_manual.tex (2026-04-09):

\documentclass[11pt,a4paper]{article}

\usepackage[utf8]{inputenc}
\usepackage[T1]{fontenc}
\usepackage[margin=1in]{geometry}
\usepackage{graphicx}
\usepackage{xcolor}
\usepackage{fancyhdr}
\usepackage{titlesec}
\usepackage{enumitem}
\usepackage{tcolorbox}
\usepackage{hyperref}

% Define tasteful colors
\definecolor{primary}{RGB}{43, 87, 154} % Elegant deep blue
\definecolor{secondary}{RGB}{95, 106, 106} % Sophisticated gray
\definecolor{accent}{RGB}{231, 76, 60} % Subtle red for warnings/cautions

% Hyperref setup for clickable links
\hypersetup{
    colorlinks=true,
    linkcolor=primary,
    filecolor=magenta,      
    urlcolor=primary,
    pdftitle={HooverTron User Manual},
    pdfauthor={HooverTron Team}
}

% Section formatting for a modern, clean look
\titleformat{\section}
  {\normalfont\Large\bfseries\color{primary}}{\thesection}{1em}{}[{\titlerule[0.8pt]}]
\titleformat{\subsection}
  {\normalfont\large\bfseries\color{secondary}}{\thesubsection}{1em}{}

% Header and Footer styling
\pagestyle{fancy}
\fancyhf{}
\fancyfoot[C]{\thepage}
\fancyhead[L]{\textcolor{secondary}{HooverTron User Manual}}
\renewcommand{\headrulewidth}{0.4pt}
\renewcommand{\footrulewidth}{0.4pt}

% Custom Tip/Warning boxes
\newtcolorbox{tipbox}{colback=primary!5!white,colframe=primary,title=Tip,fonttitle=\bfseries}
\newtcolorbox{warningbox}{colback=accent!5!white,colframe=accent,title=Warning,fonttitle=\bfseries}

% Title section
\title{\vspace{-2cm}\Huge \textbf{\textcolor{primary}{HooverTron}} \\[0.5cm] \LARGE User Manual}
\author{}
\date{\vspace{-1cm}}

\begin{document}

\maketitle
\thispagestyle{empty}

\begin{abstract}
\noindent Welcome to the HooverTron User Manual. This guide provides detailed instructions on how to set up, operate, and analyze data using the HooverTron application, an advanced clinical tool for conducting the Hoover's Sign Test with integrated sensor hardware.
\end{abstract}

\vspace{1cm}

\tableofcontents
\newpage

\section{Introduction}
HooverTron is a specialized desktop application designed to capture, visualize, and calculate objective force measurements during the Hoover's Sign Test. By communicating with external sensors, HooverTron plots real-time extension force and automatically calculates the Involuntary/Voluntary Ratio (IVVR) to provide a high-confidence objective measurement.

\section{Hardware Power \& Setup}
Before connecting the device to your computer, ensure the physical hardware is powered on and functioning.

\begin{figure}[h]
    \centering
    % TODO: Place your screenshot/photo in an 'images' folder
    
    \caption{Hardware Power setup and LED indicators}
    \label{fig:hardware-setup}
\end{figure}

\begin{enumerate}[label=\textbf{\arabic*.}]
    \item \textbf{Power On}: Press the small \textbf{white button} on the device. 
    \begin{itemize}
        \item \textit{Verification}: You should see the green light on the Arduino Nano BLE 33 begin to flash. Additionally, the battery pack's level indicator lights will glow blue.
    \end{itemize}
    \item \textbf{Power Off}: When finished with the HooverTron, double-press the small \textbf{white button}.
    \begin{itemize}
        \item \textit{Verification}: Both the flashing green Arduino light and the blue battery pack lights will turn off.
    \end{itemize}
\end{enumerate}

\section{Connecting the Device}

\subsection{Auto-Connect (Recommended)}
The HooverTron software features a convenient, automatic BLE (Bluetooth) connection capability. For the smoothest setup:
\begin{enumerate}
    \item Ensure the HooverTron hardware is powered on \textit{before} you launch the application.
    \item Upon startup, the application will automatically perform a 5-second background scan for the device.
    \item If the HooverTron is detected, the software will select it (marked with a $\star$) and connect automatically. You will see an "Auto-connecting..." message in the bottom status bar once successful.
\end{enumerate}

\subsection{Manual Connection Options}
If the device was not powered on before the application launched, or if you need to use a wired connection, follow these manual steps as shown in Figure \ref{fig:connection-menu}:

\begin{figure}[h]
    \centering
    
    \caption{Connecting the device via Bluetooth or USB}
    \label{fig:connection-menu}
\end{figure}

\begin{enumerate}[label=\textbf{\arabic*.}]
    \item \textbf{Manual Bluetooth (BLE) Connection}:
    \begin{itemize}
        \item Go to the top menu bar and select \textbf{Connection > Bluetooth > Scan for Devices}.
        \item Once the 5-second scan finishes, select the HooverTron device from the populated list and click \textbf{Connect}.
    \end{itemize}
    \item \textbf{USB (Serial) Connection}:
    \begin{itemize}
        \item Alternatively, connect via a physical USB cable.
        \item Go to \textbf{Connection > USB Connection > COM Port} and select the appropriate port for your device.
        \item You can adjust the baud rate under \textbf{Connection > USB Connection > Baud} (default is typically 19200).
    \end{itemize}
\end{enumerate}

\begin{tipbox}
Ensure the device is securely connected to the patient's leg via the straps before proceeding with the tests.
\end{tipbox}

\section{Entering Patient Information}
Once the device is connected, begin by entering the patient's information.

\begin{figure}[h]
    \centering
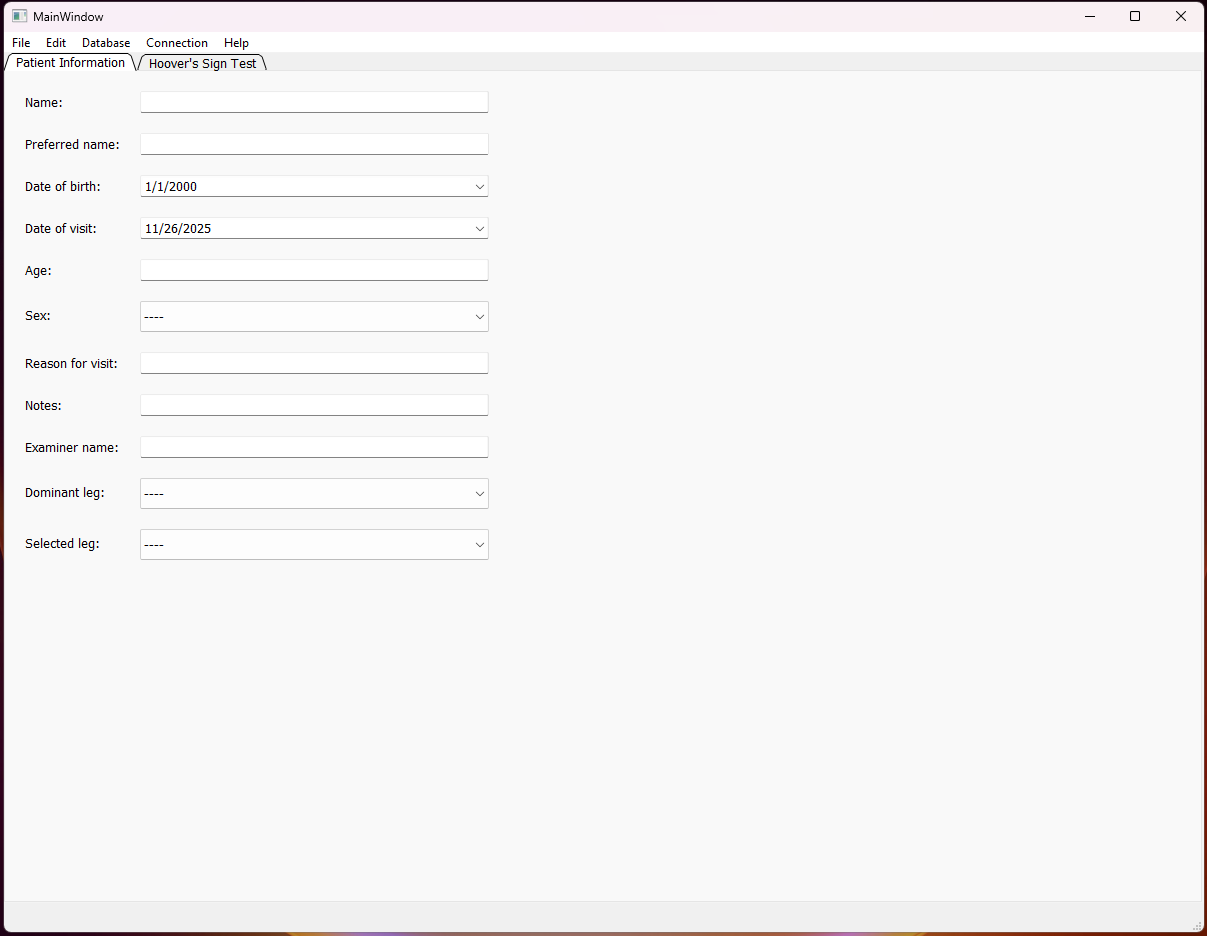
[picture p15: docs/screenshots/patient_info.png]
    
    \caption{Entering patient information in the software}
    \label{fig:patient-info}
\end{figure}

\begin{enumerate}[label=\textbf{\arabic*.}]
    \item Navigate to the \textbf{Patient Information} tab.
    \item Fill out all relevant fields:
    \begin{itemize}
        \item \textbf{Name} \& \textbf{Preferred Name}
        \item \textbf{Date of Birth} \& \textbf{Date of Visit} (The patient's age will be calculated automatically).
        \item \textbf{Sex}, \textbf{Reason for Visit}, and \textbf{Notes}.
        \item \textbf{Examiner Name}.
        \item Select the \textbf{Dominant Leg} and the \textbf{Selected Leg} (the leg primarily being evaluated) from the dropdown menus.
    \end{itemize}
\end{enumerate}

\section{Conducting the Hoover's Sign Test}
Navigate to the \textbf{Hoover's Sign Test} main tab. This tab contains three sub-tabs for the different steps of the test, plus a dedicated Results tab.

\subsection{Step 1: Unaffected Leg Extension}
This step establishes a baseline using the patient's strong/unaffected leg.
\begin{enumerate}
    \item Instruct the patient according to the infographic on the left.
    \item Click the green \textbf{Record} button to begin capturing force data. The button text will change to \textbf{Stop}.
    \item The graph will populate with real-time force measurements (in Newtons) over time.
    \item Click \textbf{Stop} when the capture is complete. 
    \item The application automatically detects the peak Extension force and displays it in the Measurements box on the right.
    \item Enter any specific observations in the Notes box.
\end{enumerate}

\begin{figure}[h]
    \centering
    
    \caption{Recording Unaffected Leg Extension with real-time force chart}
    \label{fig:step1}
\end{figure}

\subsection{Step 2: Affected Leg Voluntary Extension}
This step evaluates the voluntary strength of the patient's weak/affected leg.
\begin{enumerate}
    \item Navigate to the \textbf{Step 2} tab.
    \item Instruct the patient to perform voluntary extension on their affected leg.
    \item Click \textbf{Record} to begin capturing, and click \textbf{Stop} when done.
    \item Both the \textbf{Force Average} (dashed line) and \textbf{Force Peak} of the chosen time range will be automatically captured and displayed.
\end{enumerate}

\subsection{Step 3: Affected Leg Involuntary Extension}
This step evaluates the reflex/involuntary extension of the patient's weak leg while they flex their strong leg.
\begin{enumerate}
    \item Navigate to the \textbf{Step 3} tab.
    \item Instruct the patient as per the clinical guidelines for Hoover's Sign.
    \item Click \textbf{Record} and perform the procedure, then click \textbf{Stop}.
    \item The system will record the \textbf{Force Peak} of the involuntary extension.
\end{enumerate}

\subsection{Refining Data: Selecting a Time Period}
In any of the steps (1, 2, or 3), you might capture more data than needed (e.g., noise before or after the actual extension effort). You can isolate the valid data as shown in Figure \ref{fig:refining-data}:

\begin{figure}[h]
    \centering
    
    \caption{Refining the data by selecting a specific time period on the chart}
    \label{fig:refining-data}
\end{figure}

\begin{enumerate}
    \item On the graph, you will see a shaded vertical region.
    \item Drag the edges of this shaded region over the peaks representing the true effort.
    \item Alternatively, specify exact timestamps in the \textbf{Start Time} and \textbf{End Time} boxes below the graph and click the red \textbf{Select Time Period} button.
    \item The peak (and average) measurements will automatically update to reflect \textit{only} the data within your selected time period.
\end{enumerate}

\begin{warningbox}
Use the \textbf{Clear Data} button carefully; it will permanently wipe the data graph and measurements for that specific step.
\end{warningbox}

\section{Viewing Results and Analysis}
Once all three steps are complete, navigate to the \textbf{Results} tab.

\begin{figure}[h]
    \centering
    
    \caption{Final Results and IVVR Calculation}
    \label{fig:results}
\end{figure}

\begin{enumerate}
    \item Review the Raw Data section to ensure that the un-affected leg extension, affected leg voluntary extension (V), and affected leg involuntary extension (IV) are populated correctly.
    \item Click the large blue \textbf{Calculate Results} button.
    \item The software will automatically calculate the \textbf{Involuntary/Voluntary Ratio (IVVR)} using the formula: \texttt{IVVR = IV / V}.
    \item An analysis summary will populate at the bottom right, and you can record final overarching comments in the \textbf{Observations} box.
\end{enumerate}

\section{Managing Data (Files and Database)}
HooverTron allows you to save individual patient files as well as aggregate data into a single, comprehensive database.

\subsection{Saving an Individual Patient File}
\begin{itemize}
    \item \textbf{File > New}: Create and save a new individual \texttt{.csv} file for the current session.
    \item \textbf{File > Save}: Overwrite the currently opened \texttt{.csv} file with the latest changes.
    \item \textbf{File > Open}: Open a previously saved patient \texttt{.csv} file. It will auto-populate the graphs, patient info, and results.
\end{itemize}

\subsection{Managing the Master Database}
The Database function aggregates summary rows (one row per test) for bulk export and analysis.
\begin{itemize}
    \item \textbf{Database > Create Database}: Start a new master \texttt{.csv} file. This establishes the headers and inserts the current test as Test \#1.
    \item \textbf{Database > Open Database}: Link the application to an existing master database file so new records can be appended.
    \item \textbf{Database > Update Database}: Appends the \textit{current} test data (Patient Info, Peak Forces, and IVVR) as a new row at the bottom of the active database file.
\end{itemize}

\section{Settings and Filtering}
To ensure clean and readable charts, especially in environments susceptible to noise or tremors, HooverTron features adjustable signal filtering.

\begin{itemize}
    \item Go to \textbf{Edit > Filter Frequency} to select the smoothing level.
    \item \textbf{Heavy (5 Hz)}: Recommended for noisy environments or patients with tremors. Visually smooths the line heavily.
    \item \textbf{Standard (10 Hz)}: The default setting, providing a balance of responsiveness and smoothness.
    \item \textbf{Responsive (20 Hz)}: Best for analyzing rapid, minute movements without losing high-frequency data spikes.
\end{itemize}

\end{document}

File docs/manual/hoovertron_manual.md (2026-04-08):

# HooverTron User Manual

Welcome to the HooverTron User Manual. This guide provides detailed instructions on how to set up, operate, and analyze data using the HooverTron application, an advanced tool for conducting the Hoover's Sign Test with integrated sensor hardware.

## Table of Contents
1. [Introduction](#introduction)
2. [Hardware Power & Setup](#hardware-power--setup)
3. [Connecting the Device](#connecting-the-device)
4. [Entering Patient Information](#entering-patient-information)
5. [Conducting the Hoover's Sign Test](#conducting-the-hoovers-sign-test)
    - [Step 1: Unaffected Leg Extension](#step-1-unaffected-leg-extension)
    - [Step 2: Affected Leg Voluntary Extension](#step-2-affected-leg-voluntary-extension)
    - [Step 3: Affected Leg Involuntary Extension](#step-3-affected-leg-involuntary-extension)
    - [Refining Data: Selecting a Time Period](#refining-data-selecting-a-time-period)
6. [Viewing Results and Analysis](#viewing-results-and-analysis)
7. [Managing Data (Files and Database)](#managing-data-files-and-database)
8. [Settings and Filtering](#settings-and-filtering)

---

## Introduction

HooverTron is a specialized desktop application designed to capture, visualize, and calculate objective force measurements during the Hoover's Sign Test. By communicating with external sensors, HooverTron plots real-time extension force and automatically calculates the Involuntary/Voluntary Ratio (IVVR) to provide a high-confidence objective measurement.

## Hardware Power & Setup

Before connecting the device to your computer, ensure the physical hardware is powered on and functioning.

1. **Power On**: Press the small **white button** on the device. 
    * *Verification*: You should see the green light on the Arduino Nano BLE 33 begin to flash. Additionally, the battery pack's level indicator lights will glow blue.
2. **Power Off**: When finished with the HooverTron, double-press the small **white button**.
    * *Verification*: Both the flashing green Arduino light and the blue battery pack lights will turn off.

## Connecting the Device

Once the HooverTron hardware is powered on, connect the software:

1. **Bluetooth (BLE) Connection**:
   - Go to the top menu bar and select **Connection > Bluetooth**.
   - Select your device from the list of available BLE devices and click connect.
2. **USB (Serial) Connection**:
   - Alternatively, connect via USB.
   - Go to **Connection > USB Connection > COM Port** and select the appropriate port for your device.
   - You can also adjust the baud rate under **Connection > USB Connection > Baud** (default is typically 19200).

## Entering Patient Information

Once the device is connected, begin by entering the patient's information in the first tab.

1. Navigate to the **Patient Information** tab.
2. Fill out all relevant fields:
   - **Name** & **Preferred Name**
   - **Date of Birth** & **Date of Visit** (The patient's age will be calculated automatically).
   - **Sex**, **Reason for Visit**, and **Notes**.
   - **Examiner Name**.
   - Select the **Dominant Leg** and the **Selected Leg** (the leg primarily being evaluated) from the dropdown menus.

## Conducting the Hoover's Sign Test

Navigate to the **Hoover's Sign Test** main tab. This tab contains three sub-tabs for the different steps of the test, plus a dedicated Results tab. 

### Step 1: Unaffected Leg Extension
This step establishes a baseline using the patient's strong/unaffected leg.
1. Instruct the patient according to the infographic on the left.
2. Click the green **Record** button to begin capturing force data. The button text will change to **Stop**.
3. The graph will populate with real-time force measurements (in Newtons) over time.
4. Click **Stop** when the capture is complete. 
5. The application automatically detects the peak Extension force and displays it in the Measurements box on the right.
6. Enter any specific observations in the Notes box.

### Step 2: Affected Leg Voluntary Extension
This step evaluates the voluntary strength of the patient's weak/affected leg.
1. Navigate to the **Step 2** tab.
2. Instruct the patient to perform voluntary extension on their affected leg.
3. Click **Record** to begin capturing, and click **Stop** when done.
4. Both the **Force Average** (dashed line) and **Force Peak** of the chosen time range will be automatically captured and displayed.

### Step 3: Affected Leg Involuntary Extension
This step evaluates the reflex/involuntary extension of the patient's weak leg while they flex their strong leg.
1. Navigate to the **Step 3** tab.
2. Instruct the patient as per the clinical guidelines for Hoover's Sign.
3. Click **Record** and perform the procedure, then click **Stop**.
4. The system will record the **Force Peak** of the involuntary extension.

### Refining Data: Selecting a Time Period
In any of the steps (1, 2, or 3), you might capture more data than needed (e.g., noise before or after the actual extension effort). You can isolate the valid data:
1. On the graph, you will see a shaded vertical region.
2. Drag the edges of this shaded region over the peaks representing the true effort.
3. Alternatively, specify exact timestamps in the **Start Time** and **End Time** boxes below the graph and click the red **Select Time Period** button.
4. The peak (and average) measurements will automatically update to reflect *only* the data within your selected time period.

> [!WARNING]
> Use the **Clear Data** button carefully; it will permanently wipe the data graph and measurements for that specific step.

## Viewing Results and Analysis

Once all three steps are complete, navigate to the **Results** tab.

1. Review the Raw Data section to ensure that the un-affected leg extension, affected leg voluntary extension (V), and affected leg involuntary extension (IV) are populated correctly.
2. Click the large blue **Calculate Results** button.
3. The software will automatically calculate the **Involuntary/Voluntary Ratio (IVVR)** using the formula: `IVVR = IV / V`.
4. An analysis summary will populate at the bottom right, and you can record final overarching comments in the **Observations** box.

## Managing Data (Files and Database)

HooverTron allows you to save individual patient files as well as aggregate data into a single, comprehensive database.

### Saving an Individual Patient File
- **File > New**: Create and save a new individual `.csv` file for the current session.
- **File > Save**: Overwrite the currently opened `.csv` file with the latest changes.
- **File > Open**: Open a previously saved patient `.csv` file. It will auto-populate the graphs, patient info, and results.

### Managing the Master Database
The Database function aggregates summary rows (one row per test) for bulk export and analysis.
- **Database > Create Database**: Start a new master `.csv` file. This establishes the headers and inserts the current test as Test #1.
- **Database > Open Database**: Link the application to an existing master database file so new records can be appended.
- **Database > Update Database**: Appends the *current* test data (Patient Info, Peak Forces, and IVVR) as a new row at the bottom of the active database file.

## Settings and Filtering

To ensure clean and readable charts, especially in environments susceptible to noise or tremors, HooverTron features adjustable signal filtering.

- Go to **Edit > Filter Frequency** to select the smoothing level.
- **Heavy (5 Hz)**: Recommended for noisy environments or patients with tremors. Visually smooths the line heavily.
- **Standard (10 Hz)**: The default setting, providing a balance of responsiveness and smoothness.
- **Responsive (20 Hz)**: Best for analyzing rapid, minute movements without losing high-frequency data spikes.

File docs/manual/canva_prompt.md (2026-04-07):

# Canva Template Generation Prompt

**Instructions for the User:** Copy the text between the dashed lines below and paste it directly into Canva's "Magic Design for Presentations" prompt box (or ChatGPT/Claude, if you are asking them to draft a structured document layout). It is optimized to create a comprehensive, multi-page slide deck template with placeholders specifically designed for your software and hardware screenshots.

--------------------------------------------------------------------------------------------------

Create a highly professional, 12-slide clinical software user manual presentation template for an application called "HooverTron." 

**Design Guidelines:**
* **Visual Style:** Modern, clean, and clinical. Use a professional color palette featuring medical blue (#0078d7), crisp white, and soft light grays. 
* **Typography:** Use a clean, sans-serif font like 'Segoe UI', 'Inter', or 'Roboto'. Headings should be bold and distinct.
* **Layout:** The layout must be heavily image-driven. Every slide from Slide 3 onwards MUST include a prominent, large rectangular "Image Placeholder" occupying at least 40-50% of the slide (to be filled later with hardware photos or software screenshots).

Please generate the following 12 slides with exactly this text and structure:

**Slide 1: Title Slide**
* **Title:** HooverTron User Manual
* **Subtitle:** Objective Measurement for the Hoover's Sign Test
* **Visual:** A sleek cover design with abstract geometric medical shapes or a single large image placeholder in the background.

**Slide 2: Introduction & Overview**
* **Title:** Welcome to HooverTron
* **Body Text:** HooverTron is a specialized desktop application designed to capture, visualize, and calculate objective force measurements during the Hoover's Sign Test. By communicating with external sensors, HooverTron plots real-time extension force and automatically calculates the Involuntary/Voluntary Ratio (IVVR).
* **Layout:** Text on the left, a medium-sized image placeholder on the right.

**Slide 3: Hardware Power & Setup**
* **Title:** Powering the HooverTron Device
* **Body Text:** 
  * Turn On: Press the small white button on the device. The green light on the Arduino Nano BLE 33 will begin to flash, and the battery pack's level lights will glow blue.
  * Turn Off: Double-press the small white button. Both sets of lights will turn off.
* **Layout:** Text on the left, a large Image Placeholder on the right (for a high-quality photograph of the physical HooverTron hardware, specifically showing the white button and lights).

**Slide 4: Connecting the Device**
* **Title:** Hardware Connection
* **Body Text:** 
  1. Bluetooth: Navigate to 'Connection > Bluetooth' to select your BLE device.
  2. USB/Serial: Navigate to 'Connection > USB Connection > COM Port' to select your connected device. Baud rate defaults to 19200.
* **Layout:** Text on one side, large Image Placeholder on the other (for the menu bar drop-down screenshot).

**Slide 5: Registering Patient Information**
* **Title:** Patient Setup
* **Body Text:** Enter standard demographics (Name, DOB). Ensure you select the correct 'Dominant Leg' and 'Selected Leg' before proceeding to the test. Age is calculated automatically.
* **Layout:** Bulleted text list on the left, large Image Placeholder on the right (for the Patient tab screenshot).

**Slide 6: Step 1 - Unaffected Leg Extension**
* **Title:** Step 1: Baseline Strength
* **Body Text:** 
  * Instruct the patient to extend their strong (unaffected) leg.
  * Click 'Record' to capture real-time force data, then click 'Stop'.
  * The system automatically logs the peak extension force.
* **Layout:** Top half for the large Image Placeholder (for the graph/Step 1 tab screenshot), bottom half for the text instructions.

**Slide 7: Step 2 - Affected Leg Voluntary Extension**
* **Title:** Step 2: Voluntary Extension
* **Body Text:** 
  * Move to the Step 2 tab.
  * Instruct the patient to voluntarily perform extension on their weak (affected) leg.
  * Click 'Record'. The system captures both the Force Average and Force Peak.
* **Layout:** Top half for large Image Placeholder (for Step 2 tab screenshot), bottom half for text.

**Slide 8: Step 3 - Affected Leg Involuntary Extension**
* **Title:** Step 3: Involuntary Extension
* **Body Text:** 
  * Move to the Step 3 tab.
  * Perform the clinical Hoover's Sign maneuver: ask the patient to flex their strong leg to trigger involuntary extension in the weak leg.
  * Click 'Record'. The peak involuntary force is captured.
* **Layout:** Top half for large Image Placeholder (for Step 3 tab screenshot), bottom half for text.

**Slide 9: Refining Your Data**
* **Title:** Selecting a Time Period
* **Body Text:** If your recording contains noise, use the vertical shaded region on the graph to isolate the valid effort. You can click and drag the edges on the graph, or type specific Start/End times below and click 'Select Time Period'. Only data within this window is used for measurements.
* **Layout:** Text on the left, large Image Placeholder on the right (focused closely on the graph's shaded region selector).

**Slide 10: Results and IVVR Calculation**
* **Title:** Results and Analysis
* **Body Text:** Once all 3 steps are complete, navigate to the Results tab. Click 'Calculate Results'. The system will automatically compute the Involuntary/Voluntary Ratio (IVVR = IV / V) and provide an analysis summary. You can add distinct clinical observations here.
* **Layout:** Text on the left, very large Image Placeholder on the right (for the Results dashboard screenshot).

**Slide 11: Data Management**
* **Title:** Managing Patient Data
* **Body Text:** 
  * Individual Saves: Use File > Save / Open to manage individual patient CSVs.
  * Master Database: Use Database > Update Database to append the patient's summary metrics and IVVR ratio as a new row into the global FND patient database file.
* **Layout:** Text with icons on the left, Image Placeholder on the right.

**Slide 12: Application Settings**
* **Title:** Filter Frequency Settings
* **Body Text:** Adjust the incoming signal filter for optimal clarity:
  * Heavy (5 Hz): Ideal for patients with tremors or noisy environments.
  * Standard (10 Hz): The default balance of smoothness and fidelity.
  * Responsive (20 Hz): Best for analyzing rapid movement.
* **Layout:** Text on the left, Image Placeholder on the right (for the Edit > Filter Frequency menu screenshot).

--------------------------------------------------------------------------------------------------

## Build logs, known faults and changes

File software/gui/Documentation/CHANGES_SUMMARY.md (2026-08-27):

# Summary of Changes - BLE Implementation

## Files Modified

### 1. **HVR_code_BLE_V1/HVR_code_BLE_V1.ino** ✅
**Changes:**
- Added `#include <ArduinoBLE.h>` library
- Created BLE service with UUID "180D"
- Created BLE characteristic with UUID "2A37" (Read & Notify)
- Set device name to "HooverTron" for easy identification
- Replaced `Serial.print()` data output with `sensorDataCharacteristic.writeValue()`
- Added BLE initialization in `setup()`
- Added connection/disconnection handling in `loop()`
- Kept Serial for debugging purposes

**Functionality Preserved:**
- All sensor reading logic (A0, A1)
- All filtering algorithms (alpha, beta)
- All calibration formulas
- Data format remains the same (CSV format)
- 10ms sampling rate

### 2. **hoover_logic.py** ✅
**Changes:**
- Removed `import serial` and `QtSerialPort`
- Added `import asyncio`, `from bleak import BleakClient, BleakScanner`, and `import qasync`
- Replaced `self.serial` with `self.ble_client`
- Implemented `async def connect_ble()` for BLE connection
- Implemented `async def disconnect_ble()` for cleanup
- Implemented `notification_handler()` to receive BLE data (replaces `receive()` method)
- Updated `on_toggled()` to use async BLE connect/disconnect
- Updated `set_filter_frequency()` to send commands via BLE
- Added data buffering for fragmented BLE packets

**Functionality Preserved:**
- All UI elements and layouts
- All data processing and graphing
- File save/load operations
- Database operations  
- Data filtering and analysis
- All existing methods (file_open, file_save, clear_data, etc.)

### 3. **main.py** ✅
**Changes:**
- Added `import asyncio` and `import qasync`
- Replaced standard event loop with `qasync.QEventLoop(app)`
- Changed `sys.exit(app.exec_())` to `loop.run_forever()`

**Functionality Preserved:**
- Application startup
- Window display
- All existing initialization

### 4. **requirements.txt** ✅ (NEW FILE)
**Purpose:**
- Documents all Python dependencies
- Makes installation easier with `pip install -r requirements.txt`

**Dependencies:**
- PyQt5>=5.15.0 (GUI framework)
- bleak>=0.20.0 (BLE communication)
- qasync>=0.24.0 (async integration with PyQt5)
- numpy>=1.20.0 (data processing)
- matplotlib>=3.3.0 (plotting)

### 5. **README_BLE.md** ✅ (NEW FILE)
**Purpose:**
- Complete documentation of BLE implementation
- Installation instructions for Arduino and Python
- Usage guide
- Troubleshooting tips
- Technical specifications

## What Did NOT Change

### Application Functionality (100% Preserved)
- ✅ Data collection and visualization
- ✅ Three test tabs (Extension, Voluntary, Involuntary)
- ✅ Time period selection
- ✅ Peak and average calculations
- ✅ IVVR calculations
- ✅ Patient data management
- ✅ CSV file operations
- ✅ Database operations
- ✅ Graph plotting and display
- ✅ UI layout and appearance
- ✅ Filter frequency adjustment

### Arduino Functionality (100% Preserved)
- ✅ Sensor reading (A0, A1)
- ✅ 12-bit ADC resolution
- ✅ Force calibration formulas
- ✅ Digital filtering (alpha/beta)
- ✅ Data sampling rate (10ms)
- ✅ Filter frequency configuration

## Only Communication Method Changed

**Before:** Serial/USB (COM Port) → Wired connection
**After:** Bluetooth Low Energy (BLE) → Wireless connection

## Installation Steps

### Arduino:
1. Install ArduinoBLE library via Arduino IDE Library Manager
2. Upload HVR_code_BLE_V1.ino to Arduino Nano 33 BLE

### Python:
1. Run: `pip install -r requirements.txt`
2. Run: `python main.py`

## User Experience Changes

**Connection Process:**

**Before (Serial):**
- Select COM port from dropdown
- Click Record button
- Data flows over USB cable

**After (BLE):**
- Click Record button
- App automatically finds and connects to "HooverTron"
- Data flows wirelessly over Bluetooth

**Everything else remains identical!**

## Testing Checklist

Before deployment, verify:
- [ ] Arduino uploads successfully
- [ ] Arduino advertises as "HooverTron"
- [ ] Python app finds the device
- [ ] Connection establishes properly
- [ ] Data is received and displayed on graphs
- [ ] All three test tabs work correctly
- [ ] File save/load works
- [ ] Database operations work
- [ ] Filter frequency adjustment works over BLE
- [ ] Disconnection is clean
- [ ] Reconnection works after disconnect

## Benefits of BLE Implementation

1. **Wireless Freedom**: No USB cable required
2. **Portability**: Battery-powered operation possible
3. **Modern**: Uses contemporary communication standard
4. **Low Power**: BLE is energy efficient
5. **Range**: Works up to 10-30 meters depending on environment
6. **Cleaner Setup**: Reduces cable clutter

## Compatibility

**Hardware Requirements:**
- Arduino Nano 33 BLE (required - has built-in BLE)
- Computer with Bluetooth 4.0+ support

**Software Requirements:**
- Windows 10+ / macOS 10.15+ / Linux with BlueZ
- Python 3.7+
- Arduino IDE 1.8.10+

## Notes

- Serial debugging is still available on the Arduino at 115200 baud
- The data format and protocol remain unchanged
- BLE has lower latency than expected due to notification mode
- Maximum BLE packet size is 64 bytes (sufficient for our data)
- Connection is stable within ~10 meter range

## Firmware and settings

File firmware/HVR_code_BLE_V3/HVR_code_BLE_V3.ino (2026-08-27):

#include <ArduinoBLE.h>

// BLE Service and Characteristic
BLEService sensorService("180D"); // Custom service UUID
BLECharacteristic sensorDataCharacteristic("2A37", BLERead | BLENotify, 64); // Custom characteristic UUID with larger payload

// Variables
float xn1 = 0;
float yn1 = 0;
float xn2 = 0;
float yn2 = 0;
float xna1 = 0;
float xna2 = 0;
float Time = 0;
float alpha = 0; 
float beta = 0;  
float f = 10; // Default frequency

void setup() {
  Serial.begin(115200); // Keep serial for debugging
  
  // Keep built-in LED on to increase current draw
  pinMode(LED_BUILTIN, OUTPUT);
  digitalWrite(LED_BUILTIN, HIGH);

  // Use D2 as a "dummy load" pin — attach a 100-220 ohm resistor from D2 to GND
  pinMode(2, OUTPUT);

  // NANO 33 BLE SPECIFIC: Set ADC resolution to 12-bit (0-4095) for better precision
  analogReadResolution(12); 

  // Initialize BLE
  if (!BLE.begin()) {
    Serial.println("Starting BLE failed!");
    while (1);
  }

  // Set advertised local name and service UUID
  BLE.setLocalName("HooverTron");
  BLE.setAdvertisedService(sensorService);

  // Add the characteristic to the service
  sensorService.addCharacteristic(sensorDataCharacteristic);

  // Add service
  BLE.addService(sensorService);

  // Start advertising
  BLE.advertise();

  Serial.println("BLE device active, waiting for connections...");

  float temp = 2 * 3.14 * 0.001 * f;
  alpha = (2 - temp) / (temp + 2);
  beta = temp / (temp + 2);

  Serial.print("frequency: ");
  Serial.println(f);
  Serial.print("Alpha: ");
  Serial.println(alpha);
  Serial.print("Beta: ");
  Serial.println(beta);
}

void loop() {
  // Check for BLE connection
  BLEDevice central = BLE.central();

  // Handle Serial commands (Frequency update)
  if (Serial.available()) {
    String command = Serial.readStringUntil('\n');
    if (command.startsWith("F")) {
      f = command.substring(1).toFloat();
      float temp = 2 * 3.14 * 0.001 * f;
      alpha = (2 - temp) / (temp + 2);
      beta = temp / (temp + 2);
      Serial.print("Frequency updated to: ");
      Serial.println(f);
      
      // Send confirmation via BLE if connected
      if (central && central.connected()) {
        String confirmMsg = "Frequency updated to: " + String(f);
        sensorDataCharacteristic.writeValue(confirmMsg.c_str());
      }
    }
  }

  Time = millis();

  // Read pin A0
  int analogValue1 = analogRead(A0);
  
  // CONVERSION: The Nano 33 BLE is 12-bit (0-4095).
  float xnb1 = (analogValue1 * 5.0 / 4095.0); 

  // Read pin A1
  int analogValue2 = analogRead(A1);
  float xnb2 = (analogValue2 * 5.0 / 4095.0); 

  // Change voltage to force signal 1 and sensor 2
  xna1 = 0.8259 * exp(0.8623 * xnb1) + 0.00009463 * exp(3.163 * xnb1) - 0.825; 
  xna2 = 0.8259 * exp(0.8623 * xnb2) + 0.00009463 * exp(3.163 * xnb2) - 0.825; 
 
  // Compute the first filtered signal
  float yna1 = alpha * yn1 + beta * xna1 + beta * xn1; 

  // Compute the second filtered signal
  float yna2 = alpha * yn2 + beta * xna2 + beta * xn2; 
   
  // Store the previous values
  xn1 = xna1;
  yn1 = yna1;

  xn2 = xna2;
  yn2 = yna2;

  // Format data as comma-separated string
  String dataString = String(Time) + "," + 
                      String(xna1, 4) + "," + 
                      String(xna2, 4) + "," + 
                      String(yna1, 4);

  // Output to Serial (Always)
  Serial.println(dataString);

  // Output to BLE (If connected)
  if (central && central.connected()) {
     sensorDataCharacteristic.writeValue(dataString.c_str());
  }

  // Pulse dummy load pin to maintain current draw for battery pack
  digitalWrite(2, HIGH);
  delayMicroseconds(500);
  digitalWrite(2, LOW);

  delay(10); 
}

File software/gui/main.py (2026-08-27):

# main.py
import sys
import asyncio
import qasync
from PyQt5 import QtWidgets
from hoover_logic import HooverTronWindow

# import pyi_splash #uncomment this line and execution in main when creating distributable with a splash screen

if __name__ == "__main__":
    app = QtWidgets.QApplication(sys.argv)
    
    # Create event loop for async BLE operations
    loop = qasync.QEventLoop(app)
    asyncio.set_event_loop(loop)
    
    MainWindow = HooverTronWindow()
    MainWindow.show()
    # pyi_splash.close()
    
    with loop:
        loop.run_forever()

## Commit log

2026-08-27 reorg: clean structure, add HVR V3 firmware, remove pyc/patient csv, archive legacy
    Preserves full history: old 15 commits + new clean tree (220 files). Sheer file reduction via consolidated hardware/software/docs, .gitignore for generated.
    [Bottom.3mf, Bottom.gcode.3mf, BottomV3.3mf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]
2026-10-30 gui: update to the AntiGravity version
    Replace software/gui with the newer app from the AntiGravity working
    folder, the source of the 2026-10-01 clinician test build.
    - Light/dark theme (new ui_components/theme.py) and restyled tabs,
    patient form and results dashboard showing the IVVR
    (involuntary peak / voluntary peak)
    - Per-step data, selection ranges and confirm-to-clear on each test step
    - Autosaved drafts with recovery on start-up; patient CSVs, drafts and
    settings.json go to a "HooverTron Patients" folder beside the exe
    (beside config.py when run from source)
    - New Patient / Save / Save As workflow; saves on close
    - USB/BLE connection indicator; legs renamed affected/unaffecte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
2026-10-30 gui: record a patient ID instead of personal details
    The Patient Info tab no longer asks for the patient's name, preferred
    name, date of birth, age or sex. It records a Patient ID (letters,
    digits, '.', '_' and '-', up to 32 characters) with the examiner's
    name, visit date, reason, notes and legs.
    - Patient CSVs are named <patient-id>_<visit-date>-Visit.csv. Their
    "Patient Information:" row holds the ID, examiner, visit date,
    reason, notes, dominant leg and affected leg. Snapshots are now
    version 2.
    - Autosave starts once a patient ID is entered (it used to need a name).
    - New Patient keeps the examiner's name.
    - Files and drafts from older versions still open, but without their
    per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
